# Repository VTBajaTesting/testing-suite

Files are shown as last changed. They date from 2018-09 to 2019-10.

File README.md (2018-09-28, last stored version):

# VTBajaSAE
Virginia Tech Baja SAE - Testing Team

Welcome! This is the repository for the code that we are running on the data aquisition system. The DAQ that we are running is using a Beaglebone Black with Wifi, with the following sensors connected:

	- 4 linear potentiometers 		(shock displacement)
	- 1 Inertial measurement unit 		(orientation and general acceleration of chassis)
	- 2 Accelerometer 			(low amplitude, used for frequency analysis)
	- 1 Brake light sensor 			(contextual awareness for post processing)

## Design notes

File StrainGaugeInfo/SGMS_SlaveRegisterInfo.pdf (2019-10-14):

## Strain Gauge Measurement System (SGMS) Register Information

# Register

The following is the register used to convert analog inputs from the strain gauge circuit to I2C. This should be referenced when writing code on the master that interacts with the microcontroller. This register has a total packet size of 19 bytes.
Register Address | Register
0x00 | STATUS
0x01 | A0 - MSB
0x02 | A0 - LSB
0x03 | A1 - MSB
0x04 | A1 - LSB
0x05 | A2 - MSB
0x06 | A2 - LSB
0x07 | A3 - MSB
0x08 | A3 - LSB
0x09 | A4 - MSB
0x0A | A4 - LSB
0x0B | A5 - MSB
0x0C | A5 - LSB
0x0D | A6 -MSB
0x0E | A6 - LSB
0x0F | A7 - MSB
0x10 | A7 - LSB
0x11 | COMMANDS
0x12 | IDENTIFICATION

## Address Terminology

Note the addresses are in Hexadecimal:
- A Yellow address corresponds to a READ ONLY register
- A Green address corresponds to a READ/WRITE register

## Strain Gauge Measurement System (SGMS) Register Information

## Register Terminology

MSB - Most Significant Byte.
LSB - Least Significant Byte.
NOTE: Bytes are stored in the register in big-endian format with the MSB appearing before the LSB.

STATUS - A register address representing whether the device is actively collecting data or not. This register will be set to 0x01 if the device is collecting data and 0x00 if the device is not collecting data. (NOTE: On bootup, the STATUS register(0x00) will be set to 0x00 as the slave waits for a command from the master to start data collection).

COMMANDS - A register address used to pass commands from the master to the slave. Valid commands include:

Command | Action
0x01 | Start Data Collection
Any Other Number | Stop Data Collection

IDENTIFICATION - A register address which stores the unique identifier of the slave. This register address is useful when trying to determine which slave the data is coming from.

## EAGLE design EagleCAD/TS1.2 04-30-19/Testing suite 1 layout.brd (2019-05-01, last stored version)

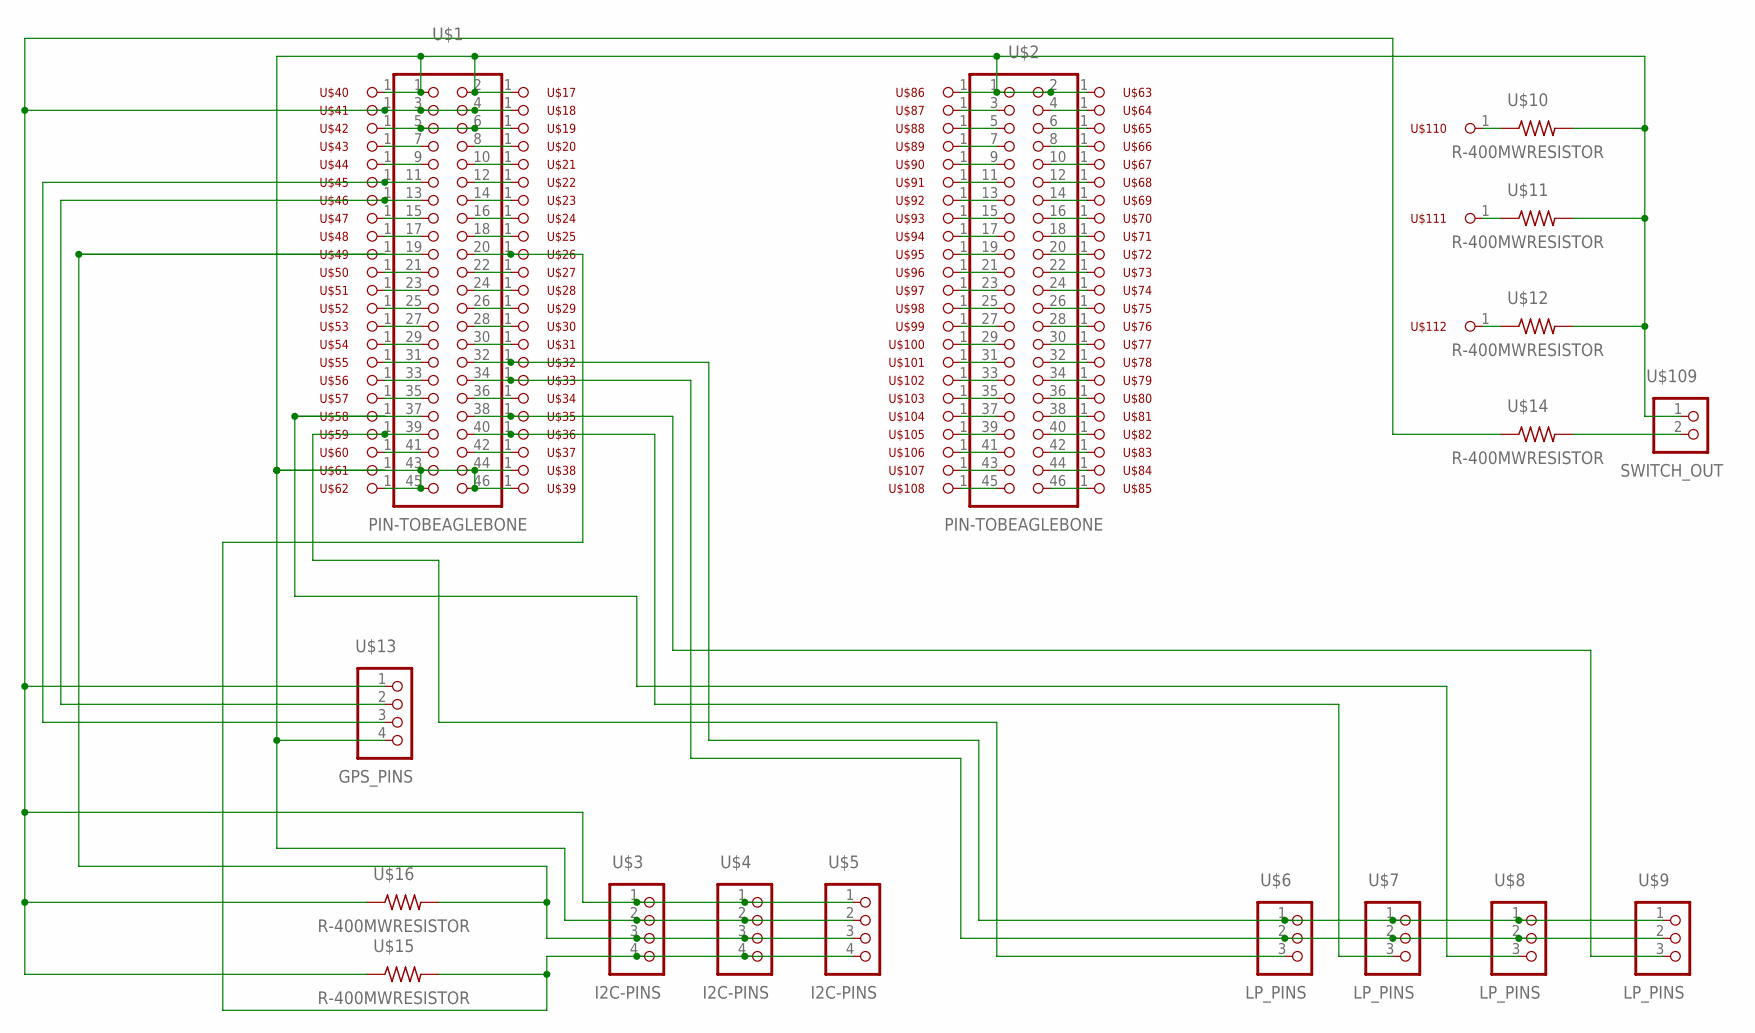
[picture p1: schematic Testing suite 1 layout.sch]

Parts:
U$1, U$2: PIN-TOBEAGLEBONE; 2X23
U$3, U$4, U$5: I2C-PINS; 1X04
U$6, U$7, U$8, U$9: LP_PINS; 1X03
U$10, U$11, U$12, U$14, U$15, U$16: R-400MWRESISTOR; 0204/7
U$13: GPS_PINS; 1X04
U$17, U$18, U$19, U$20, U$21, U$22, U$23, U$24, U$25, U$26, U$27, U$28, U$29, U$30, U$31, U$32, U$33, U$34, U$35, U$36, U$37, U$38, U$39, U$40, U$41, U$42, U$43, U$44, U$45, U$46, U$47, U$48, U$49, U$50, U$51, U$52, U$53, U$54, U$55, U$56, U$57, U$58, U$59, U$60, U$61, U$62, U$63, U$64, U$65, U$66, U$67, U$68, U$69, U$70, U$71, U$72, U$73, U$74, U$75, U$76, U$77, U$78, U$79, U$80, U$81, U$82, U$83, U$84, U$85, U$86, U$87, U$88, U$89, U$90, U$91, U$92, U$93, U$94, U$95, U$96, U$97, U$98, U$99, U$100, U$101, U$102, U$103, U$104, U$105, U$106, U$107, U$108, U$110, U$111, U$112: PAD_OUT
U$109: SWITCH_OUT; 1X02

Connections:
unnamed: U$1.39, U$6.3, U$59.1
unnamed: U$1.40, U$7.3, U$36.1
unnamed: U$1.5, U$1.6, U$19.1, U$42.1
unnamed: U$14.2, U$109.2
unnamed: U$1.37, U$8.3, U$58.1
unnamed: U$1.19, U$3.3, U$4.3, U$5.3, U$16.2, U$49.1
unnamed: U$1.20, U$3.4, U$4.4, U$5.4, U$15.2, U$26.1
unnamed: U$1.32, U$6.1, U$7.1, U$8.1, U$9.1, U$32.1
unnamed: U$1.34, U$6.2, U$7.2, U$8.2, U$9.2, U$33.1
unnamed: U$1.38, U$9.3, U$35.1
unnamed: U$1.1, U$1.2, U$1.43, U$1.44, U$1.45, U$1.46, U$2.1, U$2.2, U$3.2, U$4.2, U$5.2, U$10.2, U$11.2, U$12.2, U$13.4, U$17.1, U$38.1, U$39.1, U$40.1, U$61.1, U$62.1, U$63.1, U$86.1, U$109.1
unnamed: U$1.11, U$13.3, U$45.1
unnamed: U$1.13, U$13.2, U$46.1
unnamed: U$1.41, U$60.1
unnamed: U$1.35, U$57.1
unnamed: U$1.33, U$56.1
unnamed: U$1.31, U$55.1
unnamed: U$1.29, U$54.1
unnamed: U$1.27, U$53.1
unnamed: U$1.25, U$52.1
unnamed: U$1.23, U$51.1
unnamed: U$1.21, U$50.1
unnamed: U$1.17, U$48.1
unnamed: U$1.15, U$47.1
unnamed: U$1.9, U$44.1
unnamed: U$1.7, U$43.1
unnamed: U$1.42, U$37.1
unnamed: U$1.36, U$34.1
unnamed: U$1.30, U$31.1
unnamed: U$1.28, U$30.1
unnamed: U$1.8, U$20.1
unnamed: U$1.10, U$21.1
unnamed: U$1.12, U$22.1
unnamed: U$1.14, U$23.1
unnamed: U$1.16, U$24.1
unnamed: U$1.18, U$25.1
unnamed: U$1.22, U$27.1
unnamed: U$1.24, U$28.1
unnamed: U$1.26, U$29.1
unnamed: U$2.3, U$87.1
unnamed: U$2.5, U$88.1
unnamed: U$2.7, U$89.1
unnamed: U$2.9, U$90.1
unnamed: U$2.11, U$91.1
unnamed: U$2.13, U$92.1
unnamed: U$2.15, U$93.1
unnamed: U$2.17, U$94.1
unnamed: U$2.19, U$95.1
unnamed: U$2.21, U$96.1
unnamed: U$2.23, U$97.1
unnamed: U$2.25, U$98.1
unnamed: U$2.27, U$99.1
unnamed: U$2.28, U$76.1
unnamed: U$2.26, U$75.1
unnamed: U$2.24, U$74.1
unnamed: U$2.22, U$73.1
unnamed: U$2.20, U$72.1
unnamed: U$2.18, U$71.1
unnamed: U$2.16, U$70.1
unnamed: U$2.4, U$64.1
unnamed: U$2.6, U$65.1
unnamed: U$2.8, U$66.1
unnamed: U$2.10, U$67.1
unnamed: U$2.12, U$68.1
unnamed: U$2.14, U$69.1
unnamed: U$2.29, U$100.1
unnamed: U$2.30, U$77.1
unnamed: U$2.32, U$78.1
unnamed: U$2.31, U$101.1
unnamed: U$2.33, U$102.1
unnamed: U$2.34, U$79.1
unnamed: U$2.36, U$80.1
unnamed: U$2.35, U$103.1
unnamed: U$2.37, U$104.1
unnamed: U$2.39, U$105.1
unnamed: U$2.41, U$106.1
unnamed: U$2.43, U$107.1
unnamed: U$2.45, U$108.1
unnamed: U$2.46, U$85.1
unnamed: U$2.44, U$84.1
unnamed: U$2.42, U$83.1
unnamed: U$2.40, U$82.1
unnamed: U$2.38, U$81.1
unnamed: U$1.3, U$1.4, U$3.1, U$4.1, U$5.1, U$13.1, U$14.1, U$15.1, U$16.1, U$18.1, U$41.1
unnamed: U$10.1, U$110.1
unnamed: U$11.1, U$111.1
unnamed: U$12.1, U$112.1

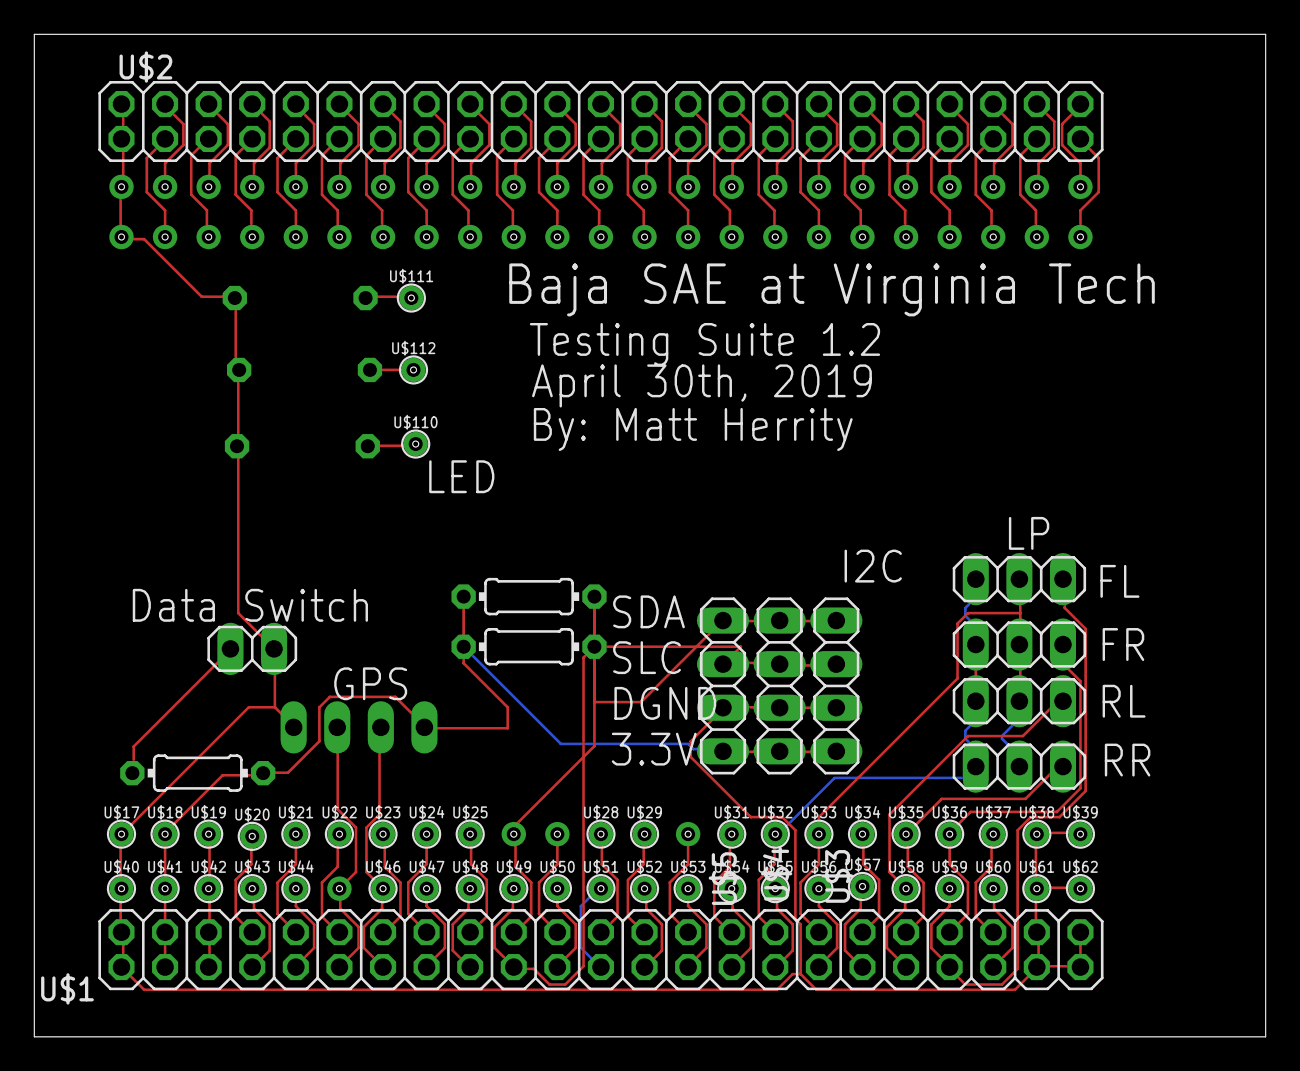
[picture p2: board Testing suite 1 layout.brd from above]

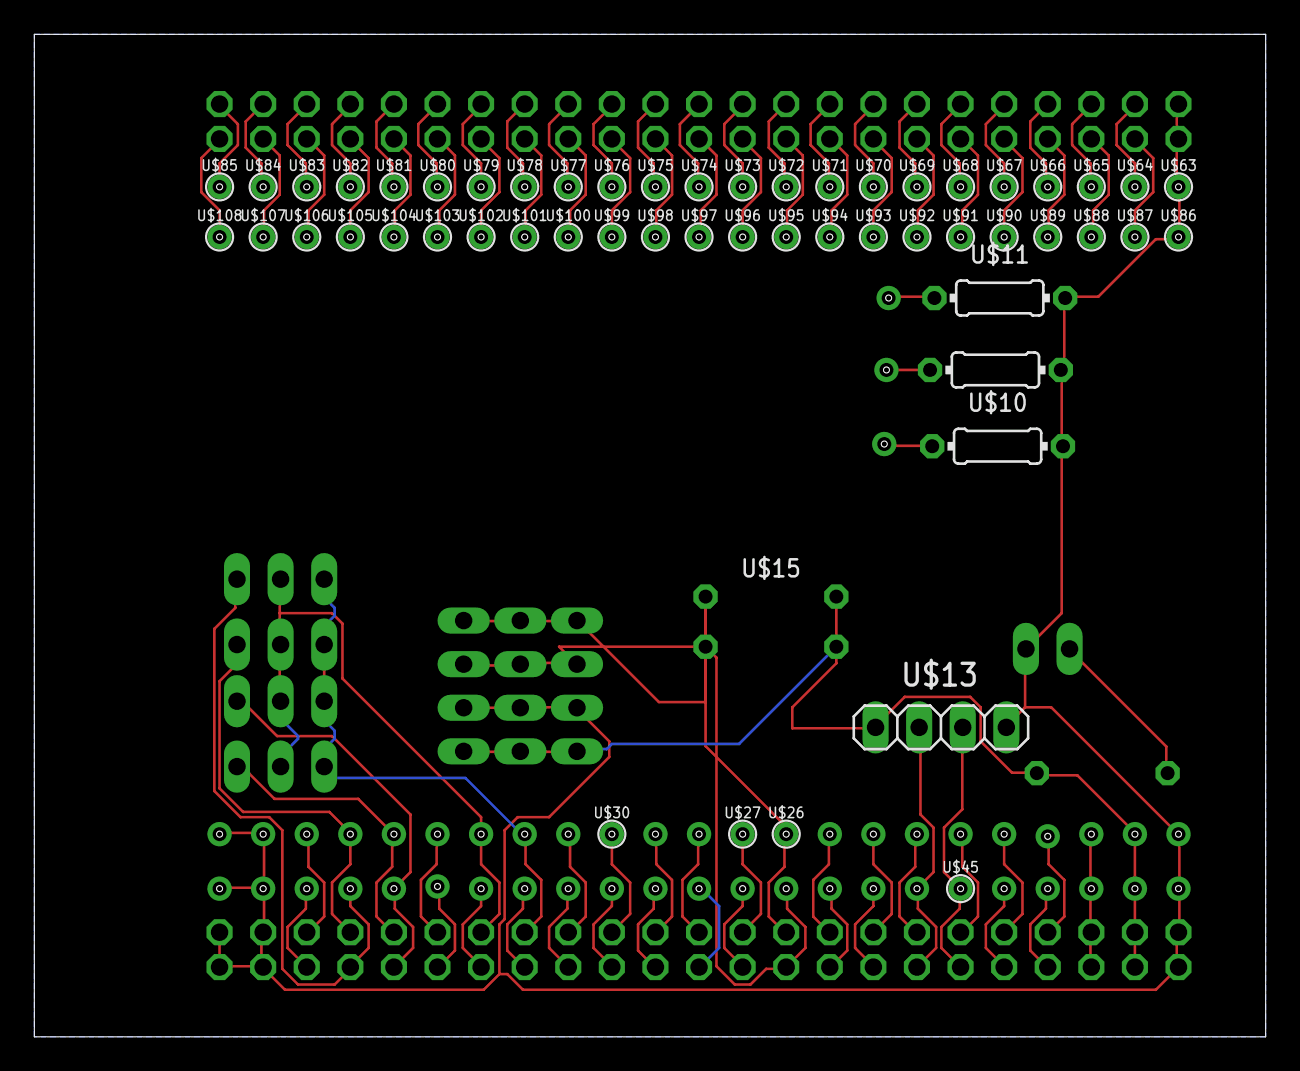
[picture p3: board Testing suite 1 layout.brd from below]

Board: 2 copper layers, 71.8 x 58.4 mm, 112 parts (54 on the bottom side), 87 nets.

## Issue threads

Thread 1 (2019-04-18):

TS 1.2 Linear Potentiometers failed

michaelb18, 2019-04-18:
Sensors did not call the read function correctly on TS1.2.

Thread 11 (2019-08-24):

Create personal local branches, and remote feature branches

michaelb18, 2019-08-24:
Make it so that each person has their own branch on their PC and Beaglebone

Make the master branch hold the code of TS 1.0(tentative)

Make the remote branch feature-threading hold code for the multithreaded testing suite

Make the remote branch feature-halleffect hold code for the hall effect sensor(if they are going to be used)

Make the remote branch feature-straingauge hold code for the strain gauges(if they are going to be used)

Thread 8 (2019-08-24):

Revert to TS 1.0 to remove sensor abstractions

michaelb18, 2019-08-24:
Polymorphism wasn't working, so revert back to TS 1.0 so that everything works again

Closed 2019-10-19.

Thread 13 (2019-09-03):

Synchronization of sensors

michaelb18, 2019-09-03:
Need a synchronized data structure that all sensors can dump their data into. At the end of execution, this data structure should be put into a .csv file

michaelb18, 2020-01-23:
There are no race conditions in the parallel testing suite right now, since threads do not write to a shared data structure.

Closed 2020-01-23.

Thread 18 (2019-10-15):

Accelerometer Remake

michaelb18, 2019-10-15:
We need to remake the Accelerometer Class so that it reads faster

michaelb18, 2019-10-15:
We need a 12 bit data structure to do this correctly, or we need to shift the bits right 20 places

michaelb18, 2019-10-19:
Accelerometer bit shifting wasn't the issue; few things were wrong, but all fixed now pending push. Closing

Closed 2019-10-19.

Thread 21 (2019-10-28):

IMU multithreading

michaelb18, 2019-10-28:
Make the IMU class have a target function to start a thread. We will need to do some linkage sorcery, but it is possible to have a member of the IMU(and other Sensor Classes) be the target function for our threads. The member function *should* (famous last words) have access to all of IMUs members.

michaelb18, 2021-08-06:
closing because multithreading breaks beaglebones

Closed 2021-08-06.

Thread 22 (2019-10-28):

Accelerometer Multithreading

michaelb18, 2019-10-28:
Make the Accelerometer class have a target function to start a thread. We will need to do some linkage sorcery, but it is possible to have a member of the Accelerometer(and other Sensor Classes) be the target function for our threads. The member function *should* (famous last words) have access to all of Accelerometer's members.

michaelb18, 2020-01-23:
@keithmyburgh - One more requirement for the Accelerometer class: the thread should end after 60 seconds or when the switch is flipped, whichever comes first.

keithmyburgh, 2020-01-24:
I thought all of the multithreading was being done in the main file. I
haven’t touched that yet, just got my code running error free while
reporting my readings in the new format

On Thu, Jan 23, 2020 at 2:09 PM Michael Bock <notifications@github.com>
wrote:

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

michaelb18, 2021-08-06:
closing because multithreading breaks beaglebones

Closed 2021-08-06.

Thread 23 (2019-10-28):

Strain Gauge multithreading

michaelb18, 2019-10-28:
Make the Strain Gauge class have a target function to start a thread. We will need to do some linkage sorcery, but it is possible to have a member of the Gauge(and other Sensor Classes) be the target function for our threads. The member function *should* (famous last words) have access to all of Strain Gauge's members.

This should be done on the master(the BeagleBone), not the slave(Arduino)

michaelb18, 2020-02-20:
This issue is currently not possible to fix due to hardware delays caused by the coronavirus.

Closed 2020-02-20.

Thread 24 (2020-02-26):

I2C Slow reads

michaelb18, 2020-02-26:
had to convert this to an issue to appease github

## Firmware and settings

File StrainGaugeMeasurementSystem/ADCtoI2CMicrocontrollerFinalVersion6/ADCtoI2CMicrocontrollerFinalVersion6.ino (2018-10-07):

/**
 * This program is responsible for converting Analog inputs from the arduino's A0-A7 pins into a value which 
 * is stored in a register and sent to the master over I2C. It has been partially adapted from a tutorial available 
 * at http://dsscircuits.com/articles/arduino-i2c-slave-guide. 
 * 
 * @version 2019.09.29
 * @author Brennan Hurst
  */
#include<Wire.h>

/**
 * The following shows how the register is setup: 
 * ADDRESS:             REGISTER:           READ/WRITE:         DESCRIPTION
 * 0x00 --------------- A0 MSB ------------ (READ ONLY) ------- N/A
 * 0x01 --------------- A0 LSB ------------ (READ ONLY) ------- N/A
 * 0x02 --------------- A1 MSB ------------ (READ ONLY) ------- N/A
 * 0x03 --------------- A1 LSB ------------ (READ ONLY) ------- N/A      
 * 0x04 --------------- A2 MSB ------------ (READ ONLY) ------- N/A
 * 0x05 --------------- A2 LSB ------------ (READ ONLY) ------- N/A
 * 0x06 --------------- A3 MSB ------------ (READ ONLY) ------- N/A
 * 0x07 --------------- A3 LSB ------------ (READ ONLY) ------- N/A
 * 0x08 --------------- A4 MSB ------------ (READ ONLY) ------- N/A
 * 0x09 --------------- A4 LSB ------------ (READ ONLY) ------- N/A
 * 0x0A --------------- A5 MSB ------------ (READ ONLY) ------- N/A
 * 0x0B --------------- A5 LSB ------------ (READ ONLY) ------- N/A
 * 0x0C --------------- A6 MSB ------------ (READ ONLY) ------- N/A
 * 0x0D --------------- A6 LSB ------------ (READ ONLY) ------- N/A
 * 0x0E --------------- A7 MSB ------------ (READ ONLY) ------- N/A
 * 0x0F --------------- A7 LSB ------------ (READ ONLY) ------- N/A
 * 0x10 --------------- IDENTIFICATION ---- (READ ONLY) ------- The unique identifier of this slave.
 */

/**
 * Definitions relating to the register. These variables can be changed 
 * in order to change the attributes of the register.
 */
#define SLAVE_ADDRESS 0x29 //The slave address (0x01 -> 0x7F)
#define REGISTER_SIZE 17 //The size of the register (bytes)
#define INTERRUPT_PIN 21 //The pin of the interrupt on this arduino
#define IDENTIFICATION 0x0D //the identification number of this device

/**
 * Create the register, register buffer, and commands arrays. 
 */
byte registerMap[REGISTER_SIZE]; //the register map for this microcontroller
byte registerMapBuffer[REGISTER_SIZE - 1]; //the register map buffer for this microcontroller

/**
 * Control variables
 */
byte arrayIndex = 0; //used as an array index when populating the register with bytes

/**
 * Measurement variables
 */
unsigned short strain0 = 0; //for A0
unsigned short strain1 = 0; //for A1
unsigned short strain2 = 0; //for A2
unsigned short strain3 = 0; //for A3
unsigned short strain4 = 0; //for A4
unsigned short strain5 = 0; //for A5
unsigned short strain6 = 0; //for A6
unsigned short strain7 = 0; //for A7

/**
 * Variables used as flags
 */
byte useInterrupt = 1; //A flag determining whether we want to use the interrupt function or not. (1 for yes, 0 for no)
byte newData = 0; //A flag set to 1 when new data has been populated in the register, otherwise it is set to 0.
/**
 * 
 * The setup() method is called on startup of the arduino microcontroller. 
 * It is responsible for seting up the pin-modes as well as the analog reference, 
 * and the i2c connection. 
  */
void setup() {
  //if we are using interrupt, setup the interrupt pins
  if (useInterrupt)
  {
    pinMode(INTERRUPT_PIN, OUTPUT);
    digitalWrite(INTERRUPT_PIN, HIGH);
  }
  //sets reference voltage to that applied to AREF pin (use tag EXTERNAL to do this)
  //for testing purposes, use DEFAULT
  analogReference(DEFAULT);
  Serial.begin(2000000);
  //set pinmodes
  pinMode(PIN_LED2, OUTPUT); //blinks once booted up and ready
  pinMode(A0, INPUT);
  pinMode(A1, INPUT);
  pinMode(A2, INPUT);
  pinMode(A3, INPUT);
  pinMode(A4, INPUT);
  pinMode(A5, INPUT);
  pinMode(A6, INPUT);
  pinMode(A7, INPUT);
  
  //setup i2c interface
  Wire.begin(SLAVE_ADDRESS);
  //setup wire request function calls
  Wire.onRequest(requestEvent);
  //set identifier of this device (permanent so we can set it permanently in registerMap.
  registerMap[REGISTER_SIZE - 1] = IDENTIFICATION;
  
}


/**
 * The toggleInterrupt() method determines if new data exists and writes a low signal to
 * the interrupt pin to let the master know data is available. 
 * If no new data is available, the interrupt pin is set to high. 
 */
void toggleInterrupt()
{
  if (!useInterrupt)
  {
    return; //no sense in wasting time on this function if interrupt isnt being used. 
  }
  if (newData)
  {
    //writes a low signal to the interrupt pin to let master known data is available
    digitalWrite(INTERRUPT_PIN, LOW);
    return;
  }

  //no new data exists, write high to interrupt pin
  digitalWrite(INTERRUPT_PIN, HIGH);
}

/**
 * The loop() function is called each clock cycle. Data is 
 * collected in the loop() function and is prepared to send to 
 * the master. The loop() can NEVER TERMINATE.
 */
void loop() {
  
    if (newData == 0)
    {
      //store data from analog pins into the strain variables
      strain0 = analogRead(A0);
      strain1 = analogRead(A1);
      strain2 = analogRead(A2);
      strain3 = analogRead(A3);
      strain4 = analogRead(A4);
      strain5 = analogRead(A5);
      strain6 = analogRead(A6);
      strain7 = analogRead(A7); 
    
      //call storeData() in order to update the registerMapBuffer
      storeData();
      //set the flag that we have new data
      newData = 1;
    }
    digitalWrite(PIN_LED2, millis()>>9 &1);
    
    
  //notify the master that new data is available
  toggleInterrupt();
}
/**
 * The storeData() function is responsible for storing 
 * the strain data (acquired as shorts) as bytes in the 
 * register.
 */
void storeData()
{
  //make sure arrayIndex is set to default (0)
  arrayIndex = 0;
  
  //Store shorts as bytes in the register
  reverseStoreBytes(strain0);
  reverseStoreBytes(strain1);
  reverseStoreBytes(strain2);
  reverseStoreBytes(strain3);
  reverseStoreBytes(strain4);
  reverseStoreBytes(strain5);
  reverseStoreBytes(strain6);
  reverseStoreBytes(strain7);
  
}

/**
 * The reverseStoreBytes() method is responsible for storing 
 * the bytes into the correct spot in the register. We are storing the bytes
 * in a big-endian format so we must reverse the bytes order (because arduino
 * stores the bytes in small-endian format). By doing this, the MSB is stored
 * in the lower index in the register.
 * 
  */
void reverseStoreBytes(unsigned short data)
{
  //store shorts into 2 bytes in the register (reverse order)
  //this is done because we want the most significant byte first in the register,
  // while arduinos store data in little-endian foramt we want to store in big-endian format
  //for i2c transmission
  byte* pointer;
  pointer = (byte*)&data;
  for(int i = 1; i > -1; i--)
  {
    registerMapBuffer[arrayIndex] = pointer[i];
    
    arrayIndex++;
  }
}

/**
 * The requestEvent() method is called when the master requests
 * data from the slave. If new data is available, the registerMap is updated
 * to contain the same data as the registerMapBuffer. The interrupt is then toggled to let the 
 * master know no new data exists and the data is sent with an offset of receivedCommands[0]. 
 */
 void requestEvent()
{
  //data must exist to populate the register map
  if (newData)
  {
    //populate with new data
    for (int i = 0; i < REGISTER_SIZE - 1; i ++)
    {
      //set register map data to the register buffer data
      registerMap[i] = registerMapBuffer[i];
      
    }
  }

  //NOTE: the entire register is sent even if the master requests data from only one register. This is because 
  // it is the responsibility of the master to determine what is and isn't useful data from the register.
  Wire.write(registerMap, REGISTER_SIZE);
  Serial.print("Packet Sent: " );
  for (int i = 0; i < REGISTER_SIZE; i++)
  {
    Serial.print(registerMap[i]);
    Serial.print(" ");
  }
  Serial.println("");
  //set newData flag
  newData = 0;
  //Update SCL to High signal
  toggleInterrupt(); 
}

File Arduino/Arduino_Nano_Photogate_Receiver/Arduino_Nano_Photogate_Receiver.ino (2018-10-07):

/*
  Andrew Touzinsky -- 10/04/18

  This code is the receiver of the photogates. To specify what this code does, we setup the radio
  communication with an address to the other tranceiver of 00101, and reads from the distance sensor
  with a set threshhold value to determine when the photogate has been passed infront of. Then it
  waits for the Arduino_Nano_Photogate_Sender to report the threshhold has been passed, and displays
  the change in time on the LCD display.
*/

// include the library code:
#include <LiquidCrystal.h>
#include <SPI.h>
//#include <nRF24L01.h>
#include <RF24.h>

RF24 radio(9, 10); // CE, CSN
const byte address[6] = "00101";

#define IRSensor A6 // Sharp IR GP2Y0A41SK0F (4-30cm, analog)
int threshbump = 0;

// initialize the library by associating any needed LCD interface pin
// with the arduino pin number it is connected to
const int rs = 2, en = 3, d4 = 4, d5 = 5, d6 = 6, d7 = 7;
int ReceivedMessage[1] = {000};
LiquidCrystal lcd(rs, en, d4, d5, d6, d7);

long starttime = 0;
long elapsedtime = 0;
long livetime = 0;

void setup() {
  // set up the LCD's number of columns and rows:
  lcd.begin(16, 2);
  // Print a message to the LCD.
  lcd.print("Time elapsed:");

  Serial.begin(9600);
  radio.begin();
  radio.openReadingPipe(1, address);
  radio.setPALevel(RF24_PA_MAX);
  radio.startListening();
}

void loop() {
  // 5v
  float volts = analogRead(IRSensor) * 0.0048828125; // value from sensor * (5/1024)
  int distance = 13 * pow(volts, -1.1); // worked out from datasheet graph
  int mean = 0; // every iteration resetting the mean value
  for (int i = 1; i < 50; i++) { // this averages every 50 readings into one mean
    mean = mean + distance;
  }
  mean = mean / 50; // this is the 2nd half of the averaging
  Serial.println(mean);

  // This section sets a threshhold value and looks for three sequential values that are
  // below the threshhold, and if the third passes then the car is said to be infront.
  if (mean < 20) { // 20 was chosen through experimentation, this is the minimum value
    threshbump++;
    if (threshbump >= 3) {
      starttime = millis();
      endcrossed == false;

      for (int j = 0; j < 16; j++) { //these lines just do a fancy thing across the bottom of the screen when crossed
        lcd.setCursor(j, 1);
        lcd.print("*");
        delay(50);
        lcd.setCursor(j, 1);
        lcd.print(" ");
        //        }
      }
      delay(750); // this is "debouncing"
    }
  }
  else {
    threshbump = 0;
  }



  //   set the cursor to column 0, line 1
  //   (note: line 1 is the second row, since counting begins with 0):
  if (radio.available()) {

    char text[32] = "";
    radio.read(&text, sizeof(text));
    lcd.setCursor(0, 1);
    lcd.print("            "); // This clears out the "Lost Signal!" text from the screen
    lcd.setCursor(0, 1);

    if (sizeof(text) == 1) {
      lcd.setCursor(15, 0);
      lcd.print("*");
    }
    if (sizeof(text) >= 2) {
      elapsedtime = millis() - starttime;
      lcd.print("                ");
      lcd.setCursor(0, 1);
      if (elapsedtime > 1000) { //this if statement only posts if it the timespan is over a second so that it doesn't get rounded up
        lcd.print(elapsedtime / 1000); //this is funky, because it displays the int of seconds
      }
      lcd.print("."); // this in combination with the other components helps display the seconds and decimal place properly
      elapsedtime = elapsedtime - elapsedtime / 1000 * 1000; //this just subtracts the rounded to the nearest second value from the rest
      lcd.print(elapsedtime);
      lcd.print(" sec");
      delay(1500);
    }
    else {
      livetime = millis() - starttime;
      lcd.print(livetime);
    }
  }
  else {
    lcd.setCursor(15, 0);
    lcd.print(" "); //This is an attempt at a more subtle loss of signal display
    lcd.setCursor(0, 1);
    lcd.print("Lost signal!"); // This should only trigger if nothing is being received
  }
}

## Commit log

2018-09-27 Creating a new file
    [1.fzz]
2018-09-27 Adding the file I was working on for PCB design. -ATT
    [1.fzz, Beaglebone_PCBDesign_FritzingFile.fzz]
2018-09-27 Added more detail and sensors. ATT
    [Beaglebone_PCBDesign_FritzingFile.fzz]
2018-09-28 Did changes. ATT
    [Beaglebone_PCBDesign_FritzingFile.fzz]
2018-09-29 The receiver for the photogate. ATT
    [ArduinoMini_Photogate_Receiver.fzz]
2018-10-01 Continuing work on the diagram. -ATT
    [ArduinoMini_Photogate_Receiver.fzz]
2018-10-01 This is a necessary change. ATT
    [ArduinoMini_Photogate_Transmitter.fzz, Beaglebone_PCBDesign.fzz, Beaglebone_PCBDesign_FritzingFile.fzz]
2018-10-01 Adding this usecase specific information. -ATT
    [ArduinoMini_Photogate_Transmitter.fzz]
2018-10-02 Working on it still. -ATT
    [ArduinoMini_Photogate_Transmitter.fzz]
2018-10-02 Working on design. -ATT
    [ArduinoMini_Photogate_Receiver.fzz, ArduinoMini_Photogate_Transmitter.fzz]
2018-10-02 Oh buddy, the pcb design is looking good. -ATT
    [ArduinoMini_Photogate_Receiver.fzz, ArduinoMini_Photogate_Transmitter.fzz]
2018-10-03 Added accelerometer class programmed to work withing 2g range but can easily be changed once hardware issue is fixed.
    [accel.cpp]
2018-10-03 Fixed the mode setting command. Also added a parameter to the constructor to allow for 2g, 4g, and 8g reading range and modified functions to incorporate it.
    [accel.cpp]
2018-10-04 First finish of the SD_Controller Constructor
    Primary focus was adaptive and dynamic statements depending on revision numbers and how many sensors are attached at any given moment.
    Recommendation, open the files in Visual Studio 2017. Preferably, open the .sln (Solution File) in MainControl/BBone_Baja_Telemetry.
2018-10-04 Required name change. -ATT
    [ArduinoMini_Photogate_Receiver.fzz, ArduinoNano_Photogate_Receiver.fzz, ArduinoNano_Photogate_Transmitter.fzz]
2018-10-04 Finalizing for now. -ATT
    [ArduinoNano_Photogate_Receiver.fzz]
2018-10-05 Clarifying naming. -ATT
    [ArduinoNano_Photogate_Sender.fzz]
2018-10-05 added comments to the accelerometer code
2018-10-05 added a destructor to reset registers after use
    [accel.cpp]
2018-10-06 Progress. -ATT
    [ArduinoNano_Photogate_Receiver.fzz, ArduinoNano_Photogate_Sender.fzz]
2018-10-07 BBB backup
    [TS1atTime-6110.csv, TS1atTime0.csv, TS1atTime11501.csv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]
2018-10-07 Made the testing suite parallel
    [TS1atTime11.589000.csv, TS1atTime3.238000.csv, TS1atTime69.568000.csv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]
2018-10-09 Reoriented PCB inscription. -ATT
    [ArduinoNano_Photogate_Receiver.fzz]
2018-11-05 This is sample data. -ATT
    [CarData1.csv]
2018-11-05 Added IMU class
2018-11-07 Added the accelerometer to post processing
    [CarData1.csv]
2018-11-16 Fixed IMU and resolved merge conflicts
    [IMU.cpp, main.cpp]
2018-12-05 added functionality for a switch to activate the datareading.
2018-12-12 bug fixes for first test
    [LP.cpp]
2019-02-03 Working on postprocessing. -ATT
    [CarData1.csv]
2019-02-12 TS1 code complete. Some lines are commented out and have to be commented back in once the sensors are on the testing suite.
    [PotentiometerSNo870.csv, PotentiometerSNo880.csv, PotentiometerSNo890.csv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]
2019-02-27 Added I2CSensor and Sensor super classes.
2019-03-23 Finished Sensor Abstraction and aded a slow reading GPS
    [TS11atTime0.csv, TS1atTime.csv]
2019-04-07 Added Black box to only read from GPS at competition(note untested)
    [TS11atTime0.csv]
2019-04-30 Code Update
    Includes the library for interfacing with the wireless module and a small change so the code compiles
2019-05-01 Added PCB files and location. -ATT
    [Testing suite 1 layout.brd, Testing suite 1 layout.sch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]
2019-05-01 Added eagle folder and current project. -ATT
    [Testing suite 1 layout.brd, Testing suite 1 layout.sch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]
2019-05-01 Generated gerber file and sent for print. -ATT
    [Testing suite 1 layout.brd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]
2019-09-23 Add CVT Dyno Code
    Pulled code from CVT dyno and placed here so it can be modified
    [ADC_0.csv, ADC_1.csv, ADC_10.csv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]
2019-09-26 Added code for new members; fixed i2c read speeds
    [TS1atTime-12016.csv, TS1atTime-20933.csv, TS1atTime-21475.csv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]
2019-09-29 Creation of Strain Gauge Masurement System files and adding of Arduino code for the SGMS register.
2019-09-30 update I2C code
2019-09-30 Draft of schematic for strain gauge circuit
    LTSpice XVII schematic of strain gauge wiring
2019-10-14 Launched other repositories
    Removed all irrelevant files and placed them in their own repositories
    [ADC_0.csv, ADC_1.csv, ADC_10.csv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]
2019-10-15 Remove post processing
    Moved post processing files to their own repository
    [CarData1.csv]
2019-10-25 Internet on the BBB now!
    [PotentiometerSNo870.csv, PotentiometerSNo880.csv, PotentiometerSNo890.csv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]
2019-11-07 doing stuff
    [TS1atTime-6110.csv, TS1atTime0.csv, TS1atTime11501.csv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]
